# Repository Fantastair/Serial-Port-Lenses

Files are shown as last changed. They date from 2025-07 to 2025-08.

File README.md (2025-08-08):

# 串口透镜（Serial Port Lenses）

一个可以监听串口通信内容的终端，而不影响原本的通信。

拥有 `Lite` 版本和 `Mobile` 版本。

| 功能 | SPL Lite | SPL Mobile |
| :---: | :---: | :---: |
| 监听双向通信 | ✅ | ✅ |
| 连接上位机软件 | ✅ | ✅ |
| 独立显示通信内容（自带屏幕） | | ✅ |
| 脱机使用（自带蓄电池） | | ✅ |

## SPL Lite

没有独立电源和屏幕，必须连接主机使用。

SPL Lite

## SPL Mobile

开发中...

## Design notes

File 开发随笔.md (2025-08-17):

# 串口透镜开发随笔

## 功能设想

一个小站点，串联在usart串口通信线路上，不干扰原始的通信，查看通信信息。

我不仅希望这个项目的成品能够成为开发调试的实用工具，也希望在项目制作中引入一些富有挑战性的内容。

## 概念构思

一个小长方盒，两端是通信接口，用于串联在原始通信线路上；上面是一块屏幕，实时显示通信内容；侧面有一个接口，可以连接电脑，发送监听到的信息；附加一些其他的小按钮，方便调试使用。

## 硬件设计

- #### 主控芯片

    选用STM32F103C8T6芯片作为数据监听与输出控制器，刚好有3个usart外设，两个的rx用于监听两根通信线，第三个用于和电脑通信。

    > 这一部分涉及基础的串口通信内容，没有过多的新鲜性，唯一有意思的是这次的接收实际上是窃听，属于通信中的第三者。我决定这个项目不再采用开发板搭建，而是直接自己绘制并焊接芯片外围电路。

- #### 屏幕

    本来打算用串口屏，但是我希望整个装置可以由电池独立供电，串口屏可能功耗偏高了，作为基础的文字显示需求使用裸屏即可。

    > 像素屏显示文字也是老技能了，这里也没有其他过多的需求。

- #### 电源

    采用可充电锂电池

    > 电源是所有电子系统的基础组成部分，电源的输出一般不会满足系统的需求，往往需要转换，这也是我一直十分头疼的问题。我为电赛绘制的电源模块使用的是隔离电源模块，这是我苦苦搜寻找到的最无脑也是效果最让我满意的模块，但是用在这个项目里显然不合适，我不得不再次直面低压电源转换这个问题。除此之外，还有充电电路的设计，希望网上的资源足够稳健。这也算是补全一块经验了。

- #### 主机通信

    我希望足够简单，最好是能牵一根USB线就能通信，这就需要芯片的外围电路上集成串口转USB电路，最好这个接口把充电的功能也包了。

    > C8T6 和 CH340 的原理图应该不难找，这回的电路设计有的整了。

- #### 其他附加功能

    我目前想到的一个就是不用区分两个通信线是rx还是tx，要是接反了，通过一个机械开关一键反接回来；另外要支持待机和唤醒，这个大多数MCU都有，甚至一些小芯片也有这个功能（我见过外挂的ADC采集芯片支持休眠和唤醒的）

    > 反接就是一个双刀双掷开关吧，待机需要研究一下，没怎么用过。

### 软件设计

这个没什么难度了，收发数据和显示罢了。

不过既然能和电脑连接通信，那么我的传统艺能，一个好看好用的上位机软件自然是少不了了。与电脑通信的主要目的是解决小屏幕显示信息量有限的问题。

### 外壳设计

方正小巧、舒适圆角、简约外观、3D打印。

## 25.7.7更新

第一轮设计与测试已经结束了，结果是失败的（最小系统并没有正常运行），由于第一步迈得太大了，导致我不知道是哪个环节出了问题，我一共焊了两块板子，都失败了，应该排除了焊接因素，问题主要出在电路设计上。目前的测试结果为：STlink能够识别设备，但是第一次下载了程序以后就不能下载了（我印象中第一次下载是成功了的，反正后面是下不进去），然后测试外挂晶振都没有起振（不清楚是不是探针太粗了压根没测到），供电上可能存在几处短路或设计缺陷（上电后出现引脚处冒烟现象），电源相关模块里有一个东西比较烫，摆得比较密，摸不出来是哪一个元件在发热。总之这一版问题还是比较大。

由此我决定，分阶段设计制作，首先制作一个简化版，在此基础上拓展成为最初设想的完全体。

简化版抛弃 屏幕、电池、SWD调试功能，通过串口下载程序，通过上位机显示数据，通过USB供电。

## 25.7.18更新

电赛备赛时忙里偷闲搞定了简化版的硬件设计与焊接，我保留了一个可编程控制的指示灯和可编程响应的按钮，简单写了个闪烁LED测试程序，运行没问题。这版方案省去了SWD接口，通过串口下载程序，正常运行时这个串口就用来和主机通讯。由于没有配备屏幕，所以这个方案必须搭配上位机使用，上位机写了个小开头，后面再说吧。

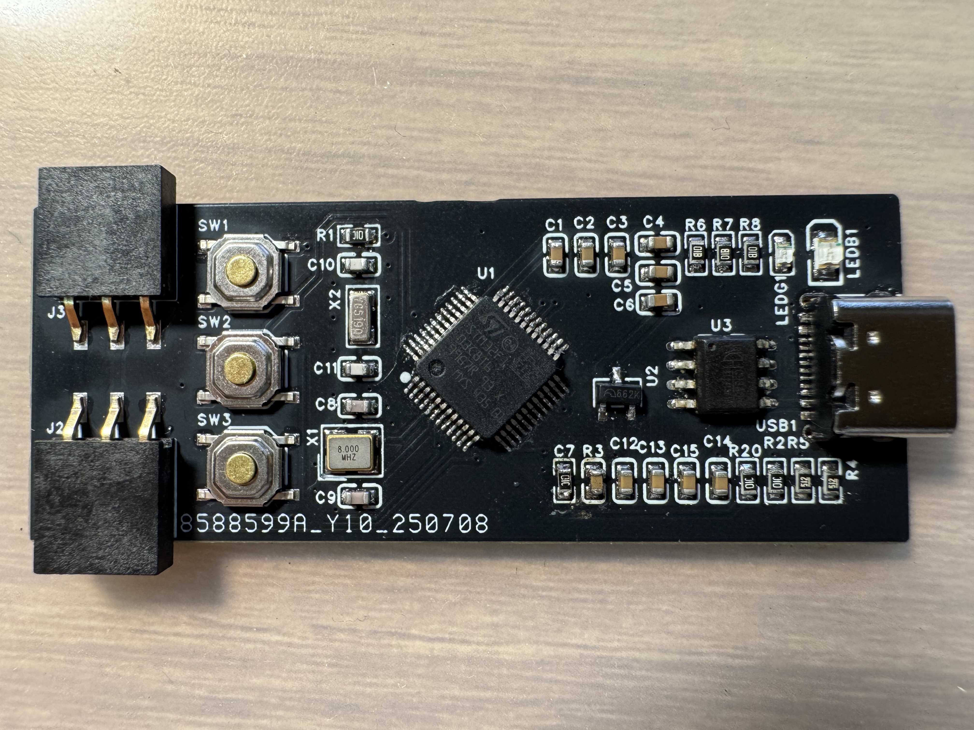
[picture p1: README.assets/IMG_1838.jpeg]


不过这个简化版的 PCB Layout 我倒是很满意，比之前的完整版要好看很多，完整版的东西太多了，我又为了使用回流焊，将所有元件都布置在正面，要改变这一点，要么使用高多层板，简化布线压力；要么换用更小的贴片封装，但是我目前的元件存货都是0603封装的，估计不好改封装。

画PCB的时候C7和R3的丝印位置放反了，测试的时候才发现一直处在复位状态，两个元件实际的位置跟着外框来，不要跟着丝印的位置焊；另外，电源指示灯（绿色LED）的限流电阻设定的是1kΩ，我觉得有点亮改成4.7kΩ了，程控指示灯是蓝色led，最早的完整版方案测试时觉得1kΩ亮度不够，这里用了2个1kΩ并联，因为我没有500Ω的电阻，感觉亮度还行了。

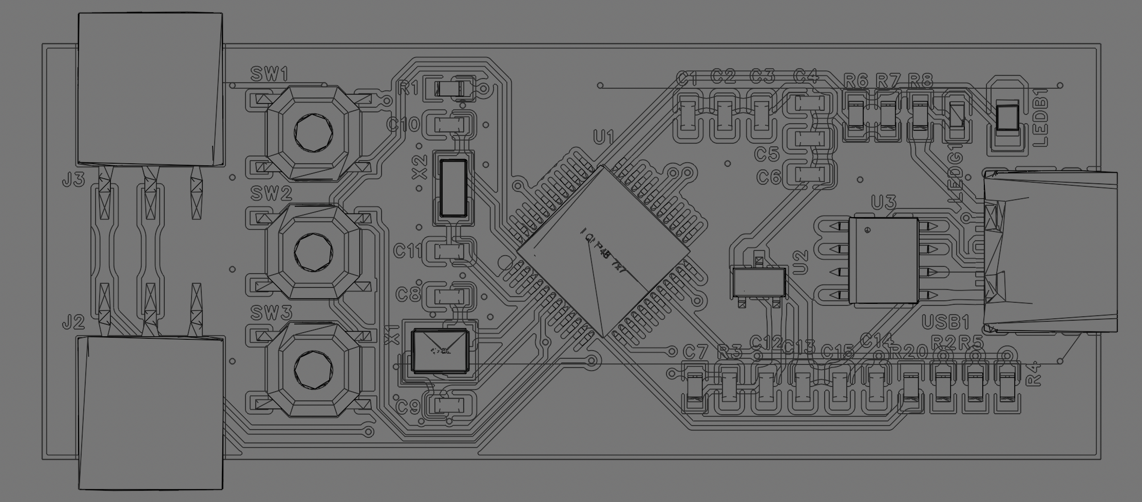
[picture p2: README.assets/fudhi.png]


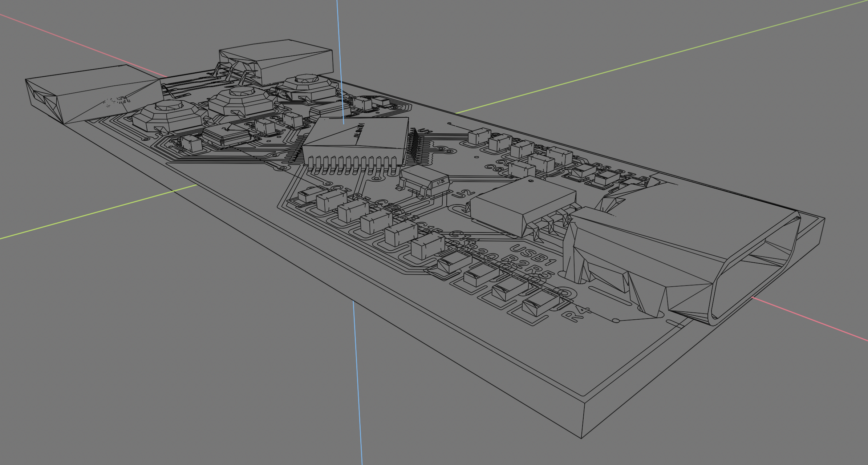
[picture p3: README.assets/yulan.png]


3D外壳的初版方案，打印出来测试尺寸没问题，但是上下盖合不上，因为我外壳给的太薄了，连接柱直接断了，等有时间了再打印一个新版本。

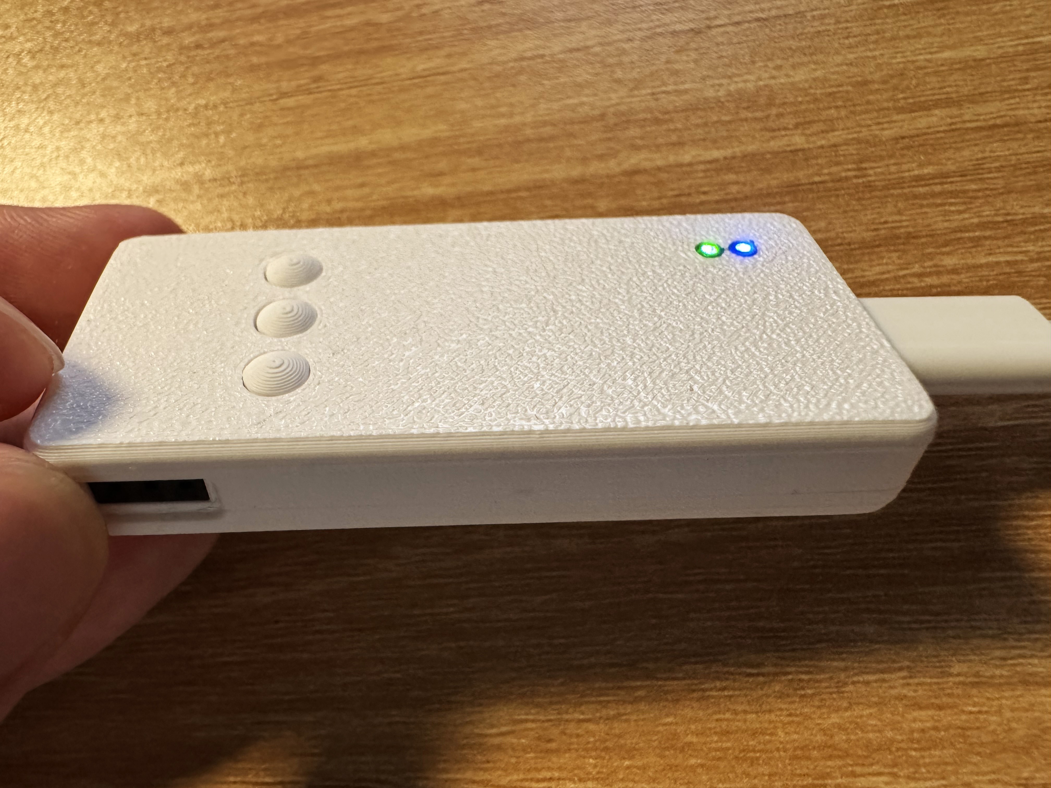
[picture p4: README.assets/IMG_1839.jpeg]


新版外壳也好了，稍微有点瑕疵，可以再微调一下，不过这看起来还真像那么回事。

三个按键自上而下依次是 `Boot` 用于进入串口下载程序，`Reset` 一键重启，`Func` 由程序自定义行为。

单片机只会在上电或重启时确定进入主程序还是串口下载程序，因此按住 `Boot` 键再按下 `Reset`，这时就会进入串口下载程序（之后可以放开 `Boot` 键），这时可以下载程序，松开 `Boot` 时再次重启即可进入主程序。

## 25.7.22更新

这两天把玩时发现目前的外壳设计的一些缺陷：

- 上下盖拼合处会漏光
- 连接柱易断裂，连接不稳固，容易摔开，摔断之后重新打了一个优化过的外壳，之后又摔了一次又断了

## 25.7.23更新

也是在几次调整之后完成了新版外壳的设计，

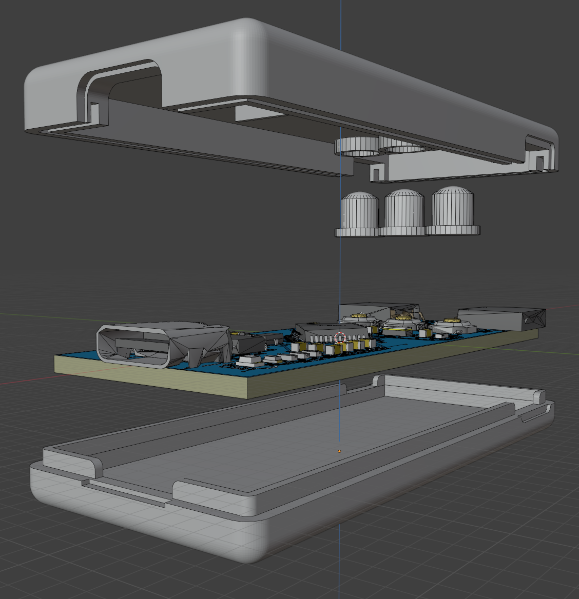
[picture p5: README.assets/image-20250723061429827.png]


新版外壳主要的改进在连接部分，不再采用单独的连接柱，而是使用整个侧边作为连接部分，既解决了强度问题，又避免了接缝漏光（材料本身透光没办法）。

确定两个版本的命名，这个简化版命名为 `SPL Lite`，完整版的则为 `SPL Mobile`。

## 25.8.8更新

完成了 `Lite` 版本的最终外壳设计。

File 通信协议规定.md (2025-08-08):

# 串口通信协议

通信数据以包的形式发送，数据包的基本格式为：

[包头] [数据包类型] [数据长度] [数据内容] [校验码] [包尾]

- 包头：0xff 0xaa

- 数据类型：

  |  类型代码   | 数据包类型 |               解释               |
  | :---------: | :--------: | :------------------------------: |
  |    0x00     |  写数据包  |           无返回数据包           |
  | 0x01 ~ 0x20 |  读数据包  | 要求对方返回一个对应的返回数据包 |
  | 0x21 ~ 0x40 | 返回数据包 |      与读数据包的编号相差32      |
  | 0x41 ~ 0xff |    保留    |                                  |

- 数据长度：数据内容长度，不包括其他部分，最大255

- 数据内容：均为单字节独立数据，需要传输更大的数字自行拆分

- 校验码：计算方式为所有数据内容累加的低 8 位再取反，校验时将校验码一并累加，如果结果为 0 则校验通过

- 包尾：0x55 0x00

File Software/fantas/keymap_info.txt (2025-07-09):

键位映射表(给人看的)
keymap文件是给程序读的(其中不包含ASCII列)

Constant      ASCII   Description
---------------------------------
K_BACKSPACE   \b      backspace
K_TAB         \t      tab
K_CLEAR               clear
K_RETURN      \r      return
K_PAUSE               pause
K_ESCAPE      ^[      escape
K_SPACE               space
K_EXCLAIM     !       exclaim
K_QUOTEDBL    "       quotedbl
K_HASH        #       hash
K_DOLLAR      $       dollar
K_AMPERSAND   &       ampersand
K_QUOTE               quote
K_LEFTPAREN   (       left parenthesis
K_RIGHTPAREN  )       right parenthesis
K_ASTERISK    *       asterisk
K_PLUS        +       plus sign
K_COMMA       ,       comma
K_MINUS       -       minus sign
K_PERIOD      .       period
K_SLASH       /       forward slash
K_0           0       0
K_1           1       1
K_2           2       2
K_3           3       3
K_4           4       4
K_5           5       5
K_6           6       6
K_7           7       7
K_8           8       8
K_9           9       9
K_COLON       :       colon
K_SEMICOLON   ;       semicolon
K_LESS        <       less-than sign
K_EQUALS      =       equals sign
K_GREATER     >       greater-than sign
K_QUESTION    ?       question mark
K_AT          @       at
K_LEFTBRACKET [       left bracket
K_BACKSLASH   \       backslash
K_RIGHTBRACKET]       right bracket
K_CARET       ^       caret
K_UNDERSCORE  _       underscore
K_BACKQUOTE   `       grave
K_a           a       a
K_b           b       b
K_c           c       c
K_d           d       d
K_e           e       e
K_f           f       f
K_g           g       g
K_h           h       h
K_i           i       i
K_j           j       j
K_k           k       k
K_l           l       l
K_m           m       m
K_n           n       n
K_o           o       o
K_p           p       p
K_q           q       q
K_r           r       r
K_s           s       s
K_t           t       t
K_u           u       u
K_v           v       v
K_w           w       w
K_x           x       x
K_y           y       y
K_z           z       z
K_DELETE              delete
K_KP0                 keypad 0
K_KP1                 keypad 1
K_KP2                 keypad 2
K_KP3                 keypad 3
K_KP4                 keypad 4
K_KP5                 keypad 5
K_KP6                 keypad 6
K_KP7                 keypad 7
K_KP8                 keypad 8
K_KP9                 keypad 9
K_KP_PERIOD   .       keypad period
K_KP_DIVIDE   /       keypad divide
K_KP_MULTIPLY *       keypad multiply
K_KP_MINUS    -       keypad minus
K_KP_PLUS     +       keypad plus
K_KP_ENTER    \r      keypad enter
K_KP_EQUALS   =       keypad equals
K_UP                  up
K_DOWN                down
K_RIGHT               right
K_LEFT                left
K_INSERT              insert
K_HOME                home
K_END                 end
K_PAGEUP              page up
K_PAGEDOWN            page down
K_F1                  F1
K_F2                  F2
K_F3                  F3
K_F4                  F4
K_F5                  F5
K_F6                  F6
K_F7                  F7
K_F8                  F8
K_F9                  F9
K_F10                 F10
K_F11                 F11
K_F12                 F12
K_F13                 F13
K_F14                 F14
K_F15                 F15
K_NUMLOCK             numlock
K_CAPSLOCK            capslock
K_SCROLLOCK           scrollock
K_RSHIFT              right shift
K_LSHIFT              left shift
K_RCTRL               right ctrl
K_LCTRL               left ctrl
K_RALT                right alt
K_LALT                left alt
K_RMETA               right meta
K_LMETA               left meta
K_LSUPER              left Windows key
K_RSUPER              right Windows key
K_MODE                mode shift
K_HELP                help
K_PRINT               print screen
K_SYSREQ              sysrq
K_BREAK               break
K_MENU                menu
K_POWER               power
K_EURO                Euro
K_AC_BACK             Android back button

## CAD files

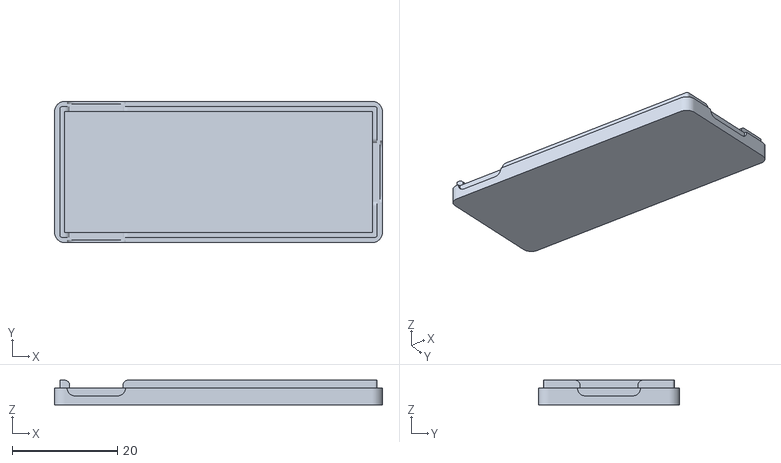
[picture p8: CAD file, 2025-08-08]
3D_Shell/底座.stl
62.4 x 26.9 x 4.70

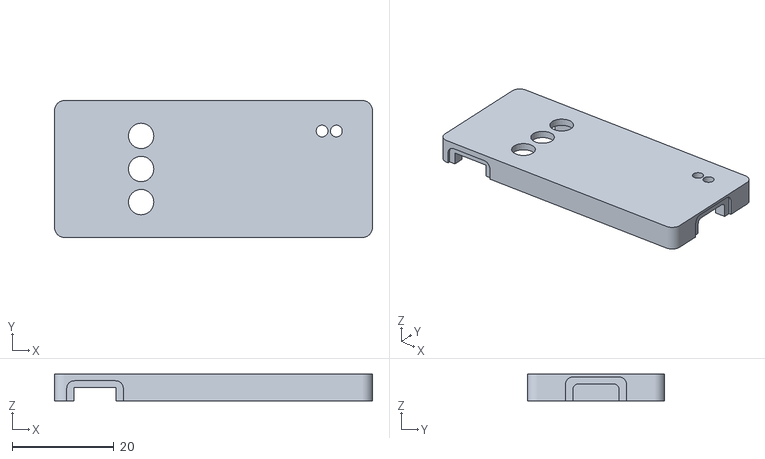
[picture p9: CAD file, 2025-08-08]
3D_Shell/顶盖.stl
62.4 x 26.9 x 5.25

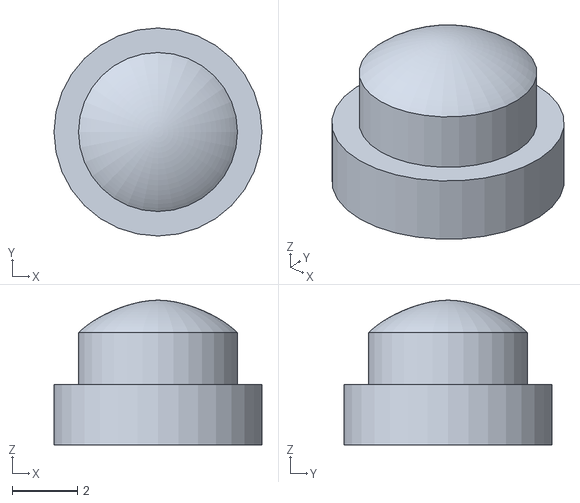
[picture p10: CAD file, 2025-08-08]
3D_Shell/按键.stl
6.40 x 6.40 x 4.45

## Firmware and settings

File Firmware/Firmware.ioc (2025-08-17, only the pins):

Mcu.UserName=STM32F103C8Tx
PA1.GPIO_Label=Func
PA1.Signal=GPXTI1
PA10.Signal=USART1_RX
PA13.Signal=SYS_JTMS-SWDIO
PA14.Signal=SYS_JTCK-SWCLK
PA2.Signal=USART2_TX
PA3.Signal=USART2_RX
PA9.Signal=USART1_TX
PB10.Signal=USART3_TX
PB11.Signal=USART3_RX
PB3.GPIO_Label=Light
PB3.Signal=S_TIM2_CH2
PD0-OSC_IN.Signal=RCC_OSC_IN
PD1-OSC_OUT.Signal=RCC_OSC_OUT

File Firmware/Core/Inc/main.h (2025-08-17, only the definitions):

#define Func_Pin GPIO_PIN_1
#define Func_GPIO_Port GPIOA
#define Func_EXTI_IRQn EXTI1_IRQn
#define Light_Pin GPIO_PIN_3
#define Light_GPIO_Port GPIOB

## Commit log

2025-06-15 初步设计与规划
2025-06-19 完成全部硬件电路设计
2025-07-09 创建固件、上位机工程
2025-07-19 track Firmware/Core/
2025-07-21 初步编写上位机
2025-07-22 上传3D外壳
2025-08-08 更新3D外壳设计
2025-08-08 update README.md and update 3D_Shell files
    [3D_Print.3mf, 底座.stl, 按键.stl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]
2025-08-17 各种乱七八糟的更新 (#2)

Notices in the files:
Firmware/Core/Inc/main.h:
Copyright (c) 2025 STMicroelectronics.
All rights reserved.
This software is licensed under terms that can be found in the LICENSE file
